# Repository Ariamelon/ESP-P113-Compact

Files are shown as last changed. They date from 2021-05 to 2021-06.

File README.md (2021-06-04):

# ESP-P113
 Compact version of ESP's Project 113 Amplifier done with SMT resistors and ceramic caps. PSU idea taken from https://theslowdiyer.wordpress.com/2019/09/10/project-files-filtered-irm-power-supplies-part-1/. Designed to go in sideways in this case (https://item.taobao.com/item.htm?id=54329725614). 

 ## Changelog
 ### V1
* 25/05/2021: Initial commit.
* 26/05/2021: Updated to V1.1. Added primary-side fuse, changed inductor to cheaper variant and rearranged components to make board even more compact. Updated BOM to match. Added extra M3 hole in middle of PCB and changed that hole to be the case grounding point instead.
* 27/05/2021: Updated to V1.2. Slightly changed position of transistors to allow for them to be mounted to an aluminium L-bracket and then to the case. 3mm power LEDs added. Changed output resistors to THT 0.5W versions. Added disclaimer on board. Moved position of components in CLC filter for more optimal routing.
 ### V2
* 29/05/2021: Updated to V2.0. A 220p compensation cap between opamp output and inverting input helped tame ringing on square waves with a 600R load with 10nF in parallel. A standard zobel network has also been added. Fixed major error with transistors (used wrong symbols/wrong way round, oops!). Added varistor between each power supply input and 3R resistor in series into live input, changed capacitor layout in output and added TVS diode to protect electronics in case converter fails as per CUI PSK-20D datasheet. 3.15A fuses into each live input will also be added off-board in the final design. Added gain switches to toggle gain resistance between 3k3 and 9k1 by switching 5k1 resistor in and out of parallel (actual resistance with both resistors in parallel is around 3k27, close enough), with option to choose between on-board DIP switches and off-board headers to use another switch. Output transistors changed to BD139/140. New layout, slightly larger but should still fit in planned case. Many thanks to user AnalogSteph on ASR for the help on the majority of the changes.
 ### V3
* 04/06/2021: Updated to V3.0. New layout with (hopefully) accurate measurements as drawings of case to be used have been received. Changed PSU to RAC20-15DK to save space and removed varistor. 200mA fuse will be used instead of 3.15A. Output BJTs changed to MJE15028/29s as they offer slightly better simulated distortion. The gain resistors have been changed to 560R/5k6 to allow for gain values of 1.5 and 6.6. PSU filter has been changed to CLC as that is more than adequate filtering. The DC protection and muting circuit from AMB has been added to protect the headphone out. On-board Y2 capacitor has been added for convenience. All SMT capacitors now also 1206 or 1210. Added 22kR/220pF RFI RC filter at the last second.

 ## Photos
Schematic
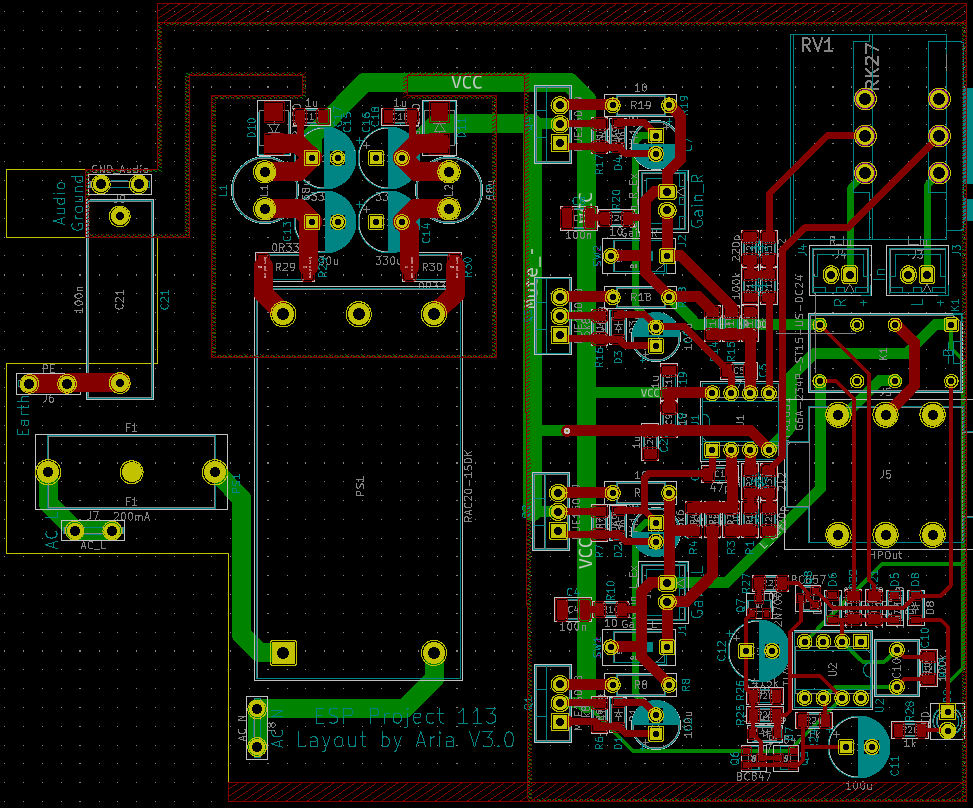
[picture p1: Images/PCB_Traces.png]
PCB Traces

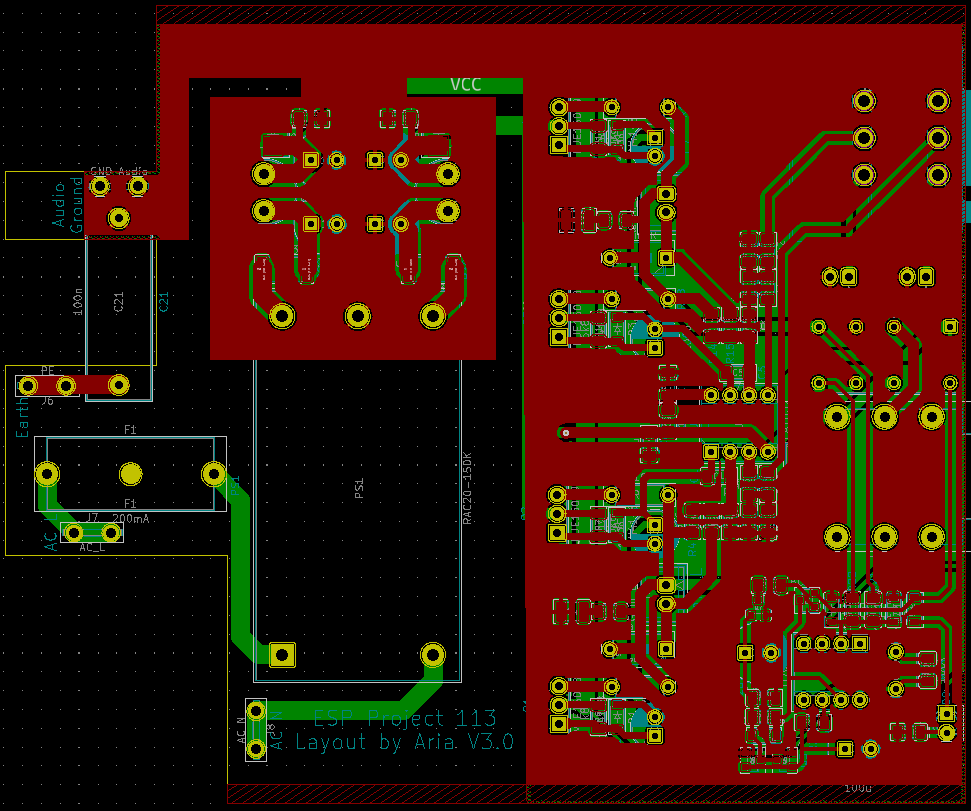
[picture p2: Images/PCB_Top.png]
Top PCB

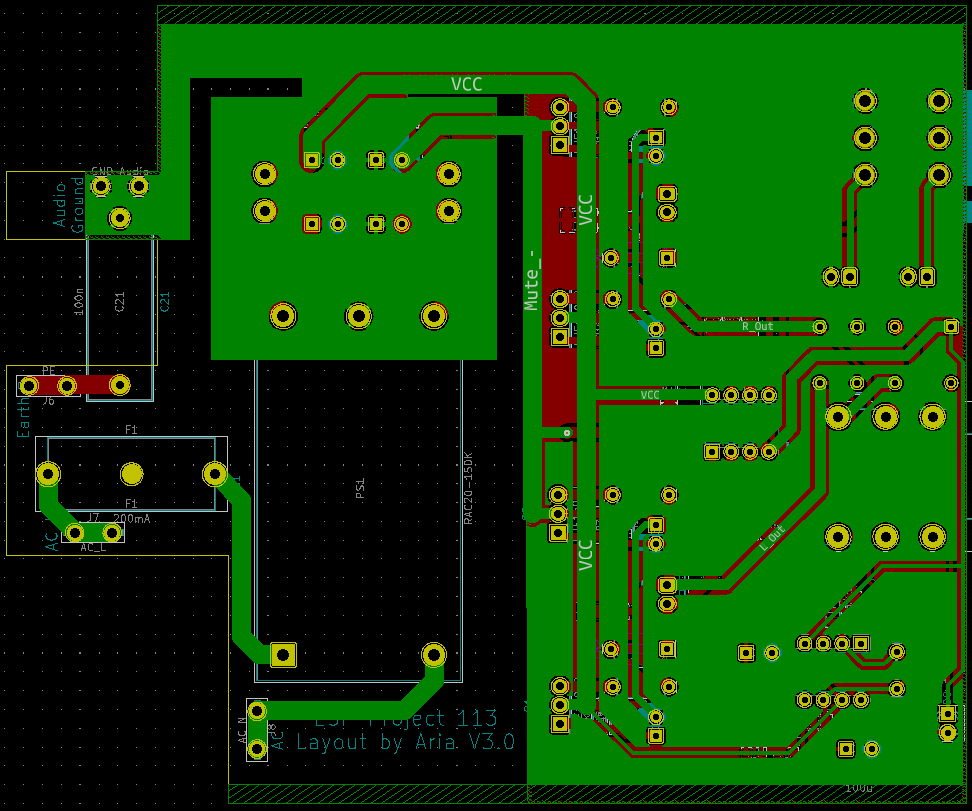
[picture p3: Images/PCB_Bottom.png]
Bottom PCB

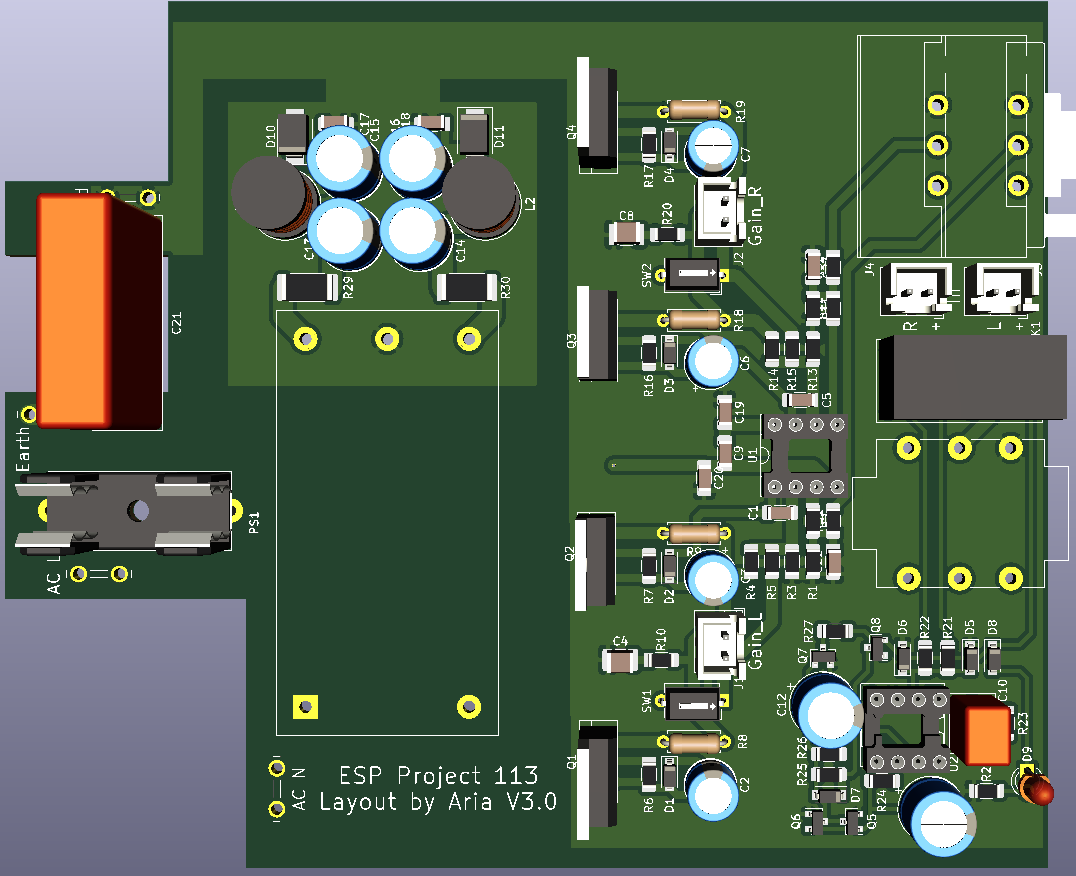
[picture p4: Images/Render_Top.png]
Top Render

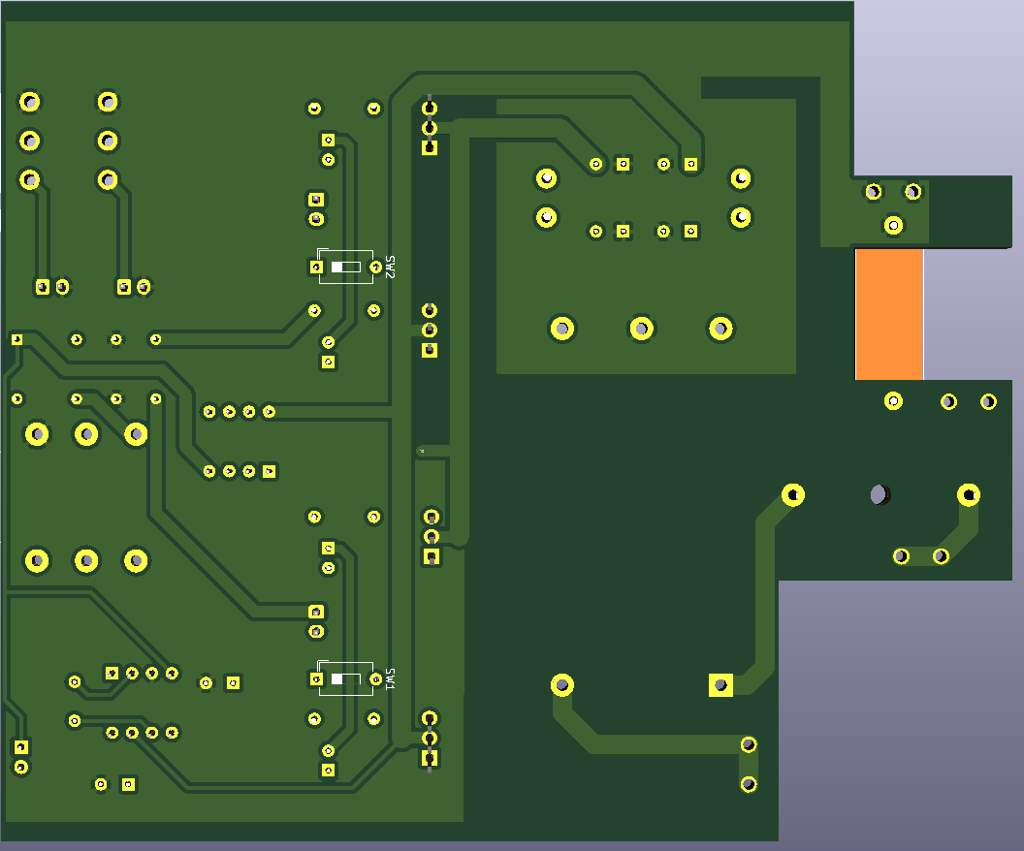
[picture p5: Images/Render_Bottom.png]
Bottom Render


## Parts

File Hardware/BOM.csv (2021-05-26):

Ref | Qnty | Value | Mfr. No | Package
C1, C5 | 2 | 1u | ECW-FE2W105JA | 18 x 5mm PP film cap, 15mm pin pacing
C2, C3, C4, C6, C7, C8, C12, C13 | 8 | 100u | EEU-FC1E101SB | 6.3mm diameter radial electrolytic, 2.5mm pin spacing
C9, C10, C11 | 3 | 100n | GCM21BR72A104KA37L | 0805 X7R capacitor
C14, C15, C16, C17 | 4 | 220u | EEU-FC1V221LB | 8mm diameter electrolytic, 3.5mm pin spacing
D1, D2, D3, D4 | 4 |  | 1N4148W-7-F | SOD-123 SMT diode
D5, D6 | 2 |  | LED_Small | 3mm LED
F1 | 1 |  | 31.8201 | 5 x 20mm fuse, greater than 0.17A
J1, J2, J3, J4 | 1 |  | B2B-XH-A(LF)(SN) | 2 position 2.54mm spacing XH2P JST connector
J5 | 1 |  | 1715721 | 2 position 5mm spacing phoenix terminal block
L1, L2 | 2 | 4u7 | TYS80404R7N-10 | 8 x 4 x 8mm inductor
PS1, PS2 | 2 | IRM-20-15 | IRM-20-15
Q1, Q3 | 2 | MJE15032 | MJE15032G | TO-220 NPN BJT
Q2, Q4 | 2 | MJE15033 | MJE15033G | TO-220 PNP BJT
R1, R9 | 2 | 22k | RT1206FRE0722KL | 1206 thin film resistor
R2, R3, R10, R11, R17, R18 | 6 | 1k | RT1206FRE071KL | 1206 thin film resistor
R4, R12 | 2 | 3k3 | RT1206FRE073K3L | 1206 thin film resistor
R5, R6, R13, R14 | 4 | 6k8 | RT1206FRE076K8L | 1206 thin film resistor
R7, R8, R15, R16 | 4 | 10 | RT1206FRE0710RL | 1206 thin film resistor
U1 | 1 | LM4562 | LM4562NA/NOPB | DIP-8 opamp

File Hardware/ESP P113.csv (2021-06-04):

Ref | Qty | Value | Cmp name | Description | Vendor
C1, C5, | 2 | 47p 50v 1% | 12061A470FAT2A | 1206 MLCC C0G/NP0
C2, C3, C6, C7, | 4 | 100u 25v 20% | EEU-FM1E101H | 6.3mmD x 11mmH x 2.5mmP radial electrolytic
C4, C8, | 2 | 100n 50v 5% | CB027D0104JBA | 1210 Metallized film
C9, C17, C18, C19, C20, | 5 | 1u 35v 20% | 1206DC105MAT2A | 1206 MLCC X7R
C10, | 1 | 1u 63v 10% | MKS2C041001F00KSSD | 7.2mmL x 5mmW x 10mmH x 5mmP radial box capacitor
C11, C12, | 2 | 100u 25v 20% | UVP1E101MPD1TA | 8mmD x 11.5mmH x 3.5mmP radial unpolarized electrolytic
C13, C14, C15, C16, | 4 | 330u 25v 20% | EEU-FC1E331L | 8mmD x 15mmH x 3.5mmP radial electrolytic, ESR is specially chosen
C21, | 1 | 100n 305vac 20% | F340Y241030MIM2T0 | 26mmL x 8.5mmW x 18mmH x 22.5mmP radial Y2 safety capacitor, MUST NOT BE X2
C22, C23, | 2 | 220p 6.3V 20% | 12063A221JAT2A | 1206 MLCC C0G/NP0
D1, D2, D3, D4, D5, D6, D7, D8, | 8 | 1Vf 4ns | MMSD914T3G | SOD-123 diode, must not have too high Vf and must have high recovery time
D9, | 1 | N/A | UV3TZ-405-30 | 3mm diode, choose any colour, I like purple lol
D10, D11, | 2 | 17v breakdown | SMBJ15D | TVS diode to protect circuit from voltage spikes
F1, | 1 | 200mA | 31.8201 | 5mmD x 20mmL fuse, slow-blow
J1, | 1 |  | XH2P | Optional, can use any 2.54mm pitch connector
J2, | 1 |  | XH2P | Optional, can use any 2.54mm pitch connector
J3, | 1 |  | XH2P | Optional, can use any 2.54mm pitch connector
J4, | 1 |  | XH2P | Optional, can use any 2.54mm pitch connector
J5, | 1 |  | NMJ6HCD2 | TRS socket
J6, | 1 |  | FastOn | Must be insulated
J7, | 1 |  | FastOn | Must be insulated
J8, | 1 |  | FastOn | Must be insulated
J9, | 1 |  | FastOn | Must be insulated
K1, | 1 | 2A max, 8.3mA coil, 10uA min load | G6A-234P-ST15-US-DC24 | Any relay which fits the same footprint and has similar specs can be used
L1, L2, | 2 | 68u 10% 1.2A 210mR | RLB0914-680KL | 8.7mmD x 12mmH x 5mmP Radial inductor
PS1, | 1 | +-15V 833mA each | RAC20-15DK | AC/DC converter
Q1, Q3, | 2 |  | MJE15028G | TO220 NPN BJT
Q2, Q4, | 2 |  | MJE15029G | TO220 PNP BJT
Q5, Q6, | 2 |  | BC847BW,135 | SOT-23 NPN BJT
Q7, | 1 |  | 2N7002NXAKR | SOT-23 NFET
Q8, | 1 |  | BC857BW,135 | SOT-23 PNP BJT
R1, R11, R23, | 3 | 100k 1% 250mW | RT1206FRE07100KL | 1206 thin film resistor
R2, R3, R12, R13, R24, R28, | 6 | 1k 1% 250mW | RT1206FRE071KL | 1206 thin film resistor
R4, R14, | 2 | 5k6 1% 250mW | RT1206FRE075K6L | 1206 thin film resistor
R5, R15, | 2 | 560 1% 250mW | RT1206FRE07560RL | 1206 thin film resistor
R6, R7, R16, R17, | 4 | 3k3 1% 250mW | RT1206FRE073K3L | 1206 thin film resistor
R8, R9, R18, R19, | 4 | 10 1% 500mW | MFR50SFTE52-10R | 2.4mmD x 6.3mmH axial metal film resistor
R10, R20, | 2 | 10 1% 250mW | RT1206FRE0710RL | 1206 thin film resistor
R21, R22, R27, | 3 | 10k | RT1206FRE0710KL | 1206 thin film resistor
R25, R26, | 2 | 475k 1% 250mW | RT1206FRE07475KL | 1206 thin film resistor
R29, R30, | 2 | 0R33 1% 2W 50PPM | KRL3264E-C-R330-F-T1 | 2512 metal foil resistor
R31, R32, | 2 | 22k 1% 250mW | RT1206FRE0722KL | 1206 thin film resistor
RV1, | 1 | 10k | RK27112 | Dual gang potentiometer
SW1, SW2, | 2 |  | NDI01H | Low profile DIP switch, optional
U1, | 1 |  | OPA1652AID | Replace with LM4562 or OPA1642 if desired
U2, | 1 |  | TL081CPE4 | Alternatives are TL072CP, LF353N or other low-cost dual FET opamps in a DIP-8 package
 | 4 |  | 274-1AB | These or other small heatsinks should be used for the output devices

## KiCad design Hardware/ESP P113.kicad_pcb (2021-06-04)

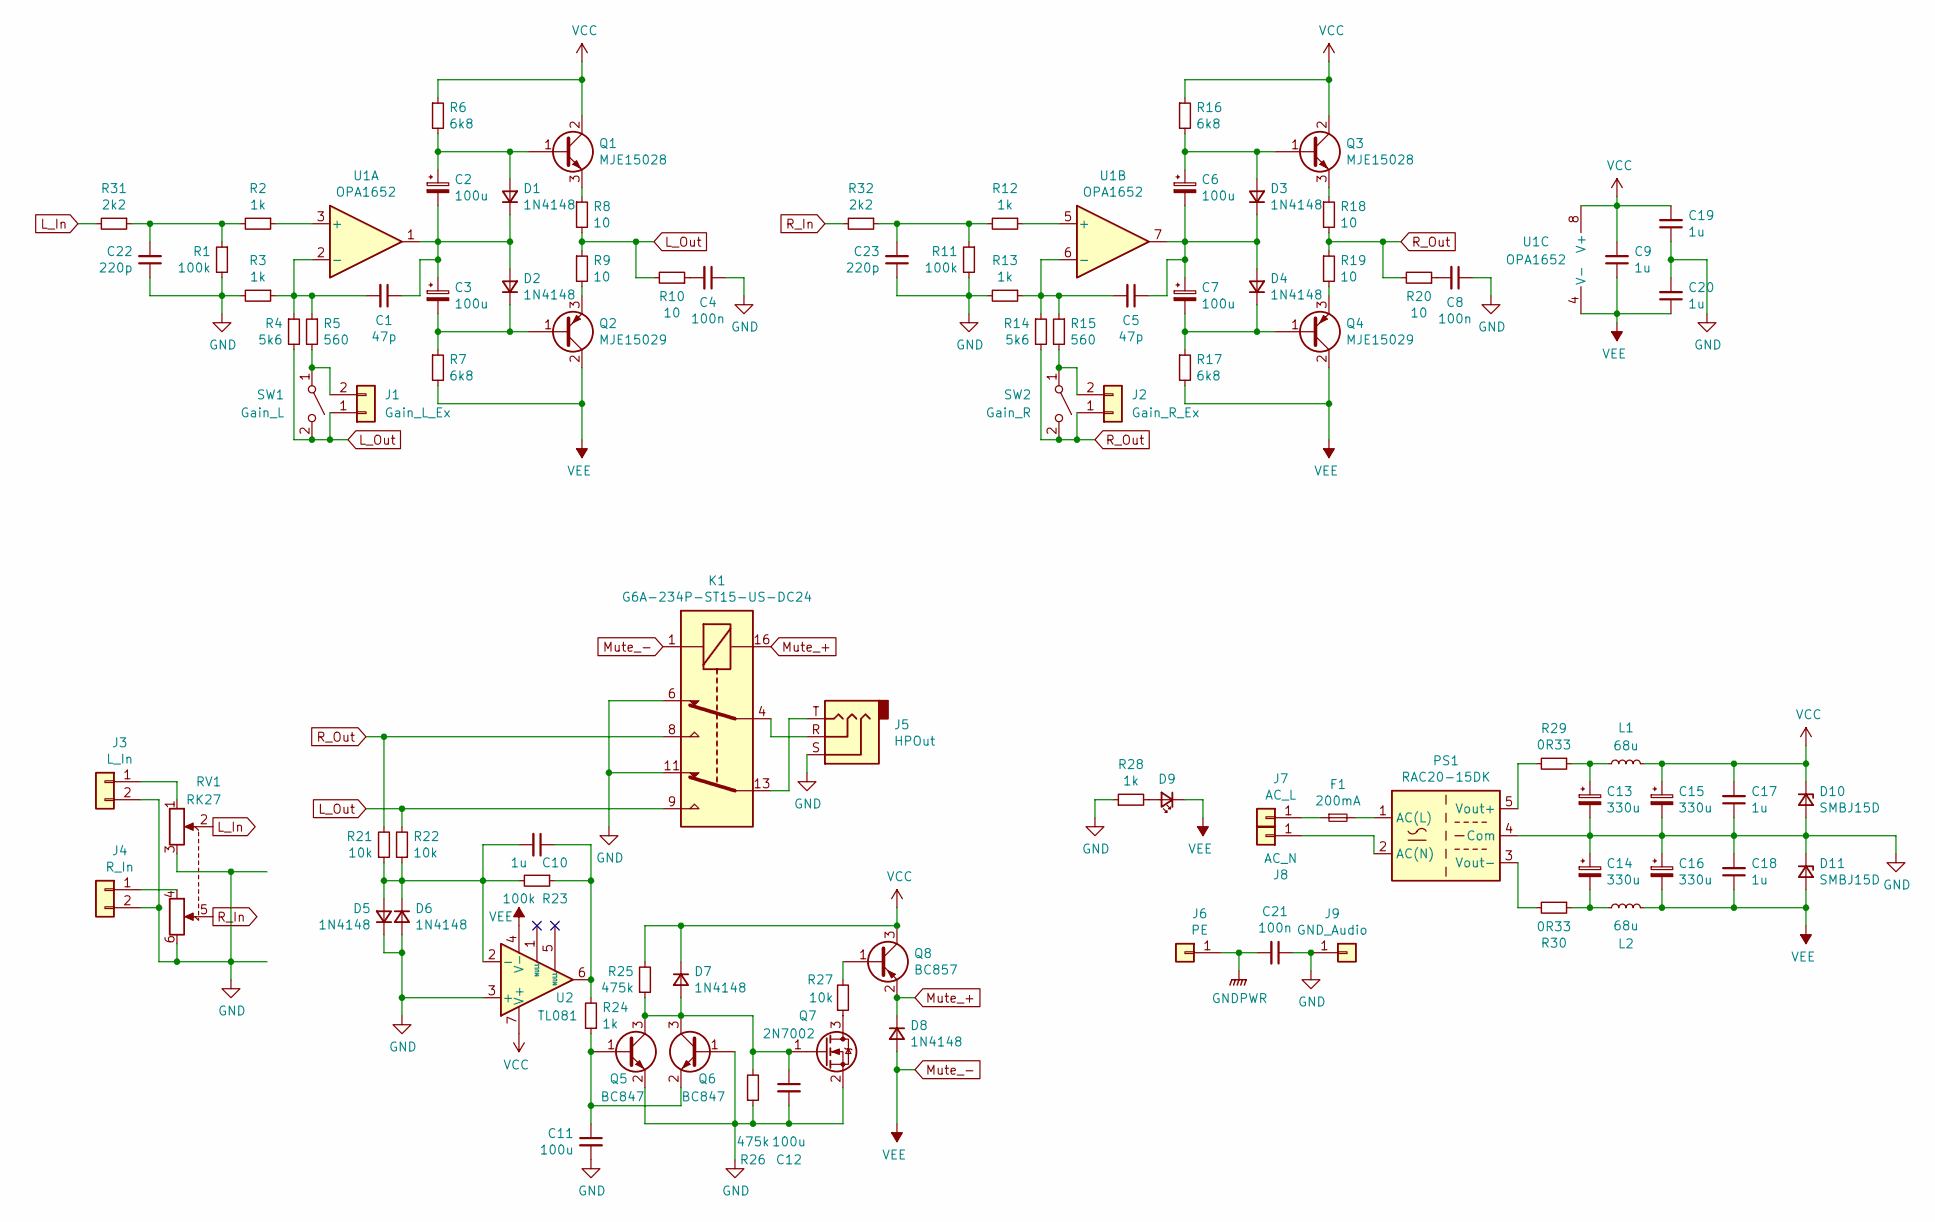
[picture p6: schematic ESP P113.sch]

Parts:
C1, C5: 47p; C_1206_3216Metric_Pad1.33x1.80mm_HandSolder
C2, C3, C6, C7: 100u; CP_Radial_D6.3mm_P2.50mm
C4, C8: 100n; C_1210_3225Metric_Pad1.33x2.70mm_HandSolder
C9, C17, C18, C19, C20: 1u; C_1206_3216Metric_Pad1.33x1.80mm_HandSolder
C10: 1u; C_Rect_L7.2mm_W5.5mm_P5.00mm_FKS2_FKP2_MKS2_MKP2
C11, C12: 100u; CP_Radial_D8.0mm_P3.50mm
C13, C14, C15, C16: 330u; CP_Radial_D8.0mm_P3.50mm
C21: 100n; C_Rect_L26.5mm_W8.5mm_P22.50mm_MKS4
C22, C23: 220p; C_1206_3216Metric_Pad1.33x1.80mm_HandSolder
D1, D2, D3, D4, D5, D6, D7, D8: 1N4148; D_SOD-123
D9: LED; LED_D3.0mm
D10, D11: SMBJ15D; D_SMB
F1: 200mA; Fuseholder_Cylinder-5x20mm_Schurter_0031_8201_Horizontal_Op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
J1: Gain_L_Ex; JST_XH_B2B-XH-A_1x02_P2.50mm_Vertical
J2: Gain_R_Ex; JST_XH_B2B-XH-A_1x02_P2.50mm_Vertical
J3: L_In; JST_XH_B2B-XH-A_1x02_P2.50mm_Vertical
J4: R_In; JST_XH_B2B-XH-A_1x02_P2.50mm_Vertical
J5: HPOut; Jack_6.35mm_Neutrik_NMJ6HCD2_Horizontal
J6: PE; FastOn
J7: AC_L; FastOn
J8: AC_N; FastOn
J9: GND_Audio; FastOn
K1: G6A-234P-ST15-US-DC24; Relay_DPDT_Omron_G5V-2
L1, L2: 68u; L_Radial_D8.7mm_P5.00mm_Fastron_07HCP
PS1: RAC20-15DK; Converter_ACDC_RACx0-DK_THT
Q1, Q3: MJE15028; TO-220-3_Vertical
Q2, Q4: MJE15029; TO-220-3_Vertical
Q5, Q6: BC847; SOT-23
Q7: 2N7002; SOT-23
Q8: BC857; SOT-23
R1, R11, R23: 100k; R_1206_3216Metric_Pad1.30x1.75mm_HandSolder
R2, R3, R12, R13, R24, R28: 1k; R_1206_3216Metric_Pad1.30x1.75mm_HandSolder
R4, R14: 5k6; R_1206_3216Metric_Pad1.30x1.75mm_HandSolder
R5, R15: 560; R_1206_3216Metric_Pad1.30x1.75mm_HandSolder
R6, R7, R16, R17: 6k8; R_1206_3216Metric_Pad1.30x1.75mm_HandSolder
R8, R9, R18, R19: 10; R_Axial_DIN0207_L6.3mm_D2.5mm_P7.62mm_Horizontal
R10, R20: 10; R_1206_3216Metric_Pad1.30x1.75mm_HandSolder
R21, R22, R27: 10k; R_1206_3216Metric_Pad1.30x1.75mm_HandSolder
R25, R26: 475k; R_1206_3216Metric_Pad1.30x1.75mm_HandSolder
R29, R30: 0R33; R_2512_6332Metric_Pad1.40x3.35mm_HandSolder
R31, R32: 2k2; R_1206_3216Metric_Pad1.30x1.75mm_HandSolder
RV1: RK27; ALPS_RK27112
SW1: Gain_L; SW_DIP_SPSTx01_Slide_6.7x4.1mm_W7.62mm_P2.54mm_LowProfile
SW2: Gain_R; SW_DIP_SPSTx01_Slide_6.7x4.1mm_W7.62mm_P2.54mm_LowProfile
U1: OPA1652; DIP-8_W7.62mm_Socket
U2: TL081; DIP-8_W7.62mm_Socket

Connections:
GND: C4.1, C8.1, C11.2, C12.2, C13.2, C14.1, C15.2, C16.1, C17.1, C18.2, C19.1, C20.2, C21.1, C22.1, C23.1, D5.1 (K), D6.2 (A), D10.2 (A), D11.1 (K), J3.2, J4.2, J5.S, J9.1, K1.6, K1.11, PS1.4 (Com), Q5.2 (E), Q6.1 (B), Q7.2 (S), R1.2, R3.2, R11.2, R13.2, R26.1, R28.1, RV1.3, RV1.6, U2.3 (+)
GNDPWR: C21.2, J6.1
L_In: R31.2, RV1.2
L_Out: J1.1, K1.9, R4.2, R8.2, R9.1, R10.2, R22.2, SW1.2 (B)
Mute_+: D8.1 (K), K1.16, Q8.2 (E)
Mute_-: C9.1, C16.2, C18.1, C20.1, D8.2 (A), D9.1 (K), D11.2 (A), K1.1, L2.2, Q2.2 (C), Q4.2 (C), R7.2, R17.2, U1.4 (V-), U2.4 (V-)
unnamed: C1.1, C2.2, C3.1, D1.1 (K), D2.2 (A), U1.1
unnamed: C1.2, R3.1, R4.1, R5.1, U1.2 (-)
unnamed: C2.1, D1.2 (A), Q1.1 (B), R6.2
unnamed: C3.2, D2.1 (K), Q2.1 (B), R7.1
unnamed: C4.2, R10.1
unnamed: C5.1, C6.2, C7.1, D3.1 (K), D4.2 (A), U1.7
unnamed: C5.2, R13.1, R14.1, R15.1, U1.6 (-)
unnamed: C6.1, D3.2 (A), Q3.1 (B), R16.2
unnamed: C7.2, D4.1 (K), Q4.1 (B), R17.1
unnamed: C8.2, R20.1
unnamed: C10.1, R23.1, R24.2, U2.6
unnamed: C10.2, D5.2 (A), D6.1 (K), R21.1, R22.1, R23.2, U2.2 (-)
unnamed: C11.1, Q5.1 (B), Q6.2 (E), R24.1
unnamed: C12.1, D7.2 (A), Q5.3 (C), Q6.3 (C), Q7.1 (G), R25.1, R26.2
unnamed: C13.1, L1.1, R29.1
unnamed: C14.2, L2.1, R30.1
unnamed: C22.2, R1.1, R2.2, R31.1
unnamed: C23.2, R11.1, R12.2, R32.1
unnamed: D9.2 (A), R28.2
unnamed: F1.1, J7.1
unnamed: F1.2, PS1.1 (AC(L))
unnamed: J1.2, R5.2, SW1.1 (A)
unnamed: J2.2, R15.2, SW2.1 (A)
unnamed: J3.1, RV1.1
unnamed: J4.1, RV1.4
unnamed: J5.R, K1.4
unnamed: J5.T, K1.13
unnamed: J8.1, PS1.2 (AC(N))
unnamed: PS1.3 (Vout-), R30.2
unnamed: PS1.5 (Vout+), R29.2
unnamed: Q1.3 (E), R8.1
unnamed: Q2.3 (E), R9.2
unnamed: Q3.3 (E), R18.1
unnamed: Q4.3 (E), R19.2
unnamed: Q7.3 (D), R27.1
unnamed: Q8.1 (B), R27.2
unnamed: R2.1, U1.3 (+)
unnamed: R12.1, U1.5 (+)
R_In: R32.2, RV1.5
R_Out: J2.1, K1.8, R14.2, R18.2, R19.1, R20.2, R21.2, SW2.2 (B)
VCC: C9.2, C15.1, C17.2, C19.2, D7.1 (K), D10.1 (K), L1.2, Q1.2 (C), Q3.2 (C), Q8.3 (C), R6.1, R16.1, R25.2, U1.8 (V+), U2.7 (V+)

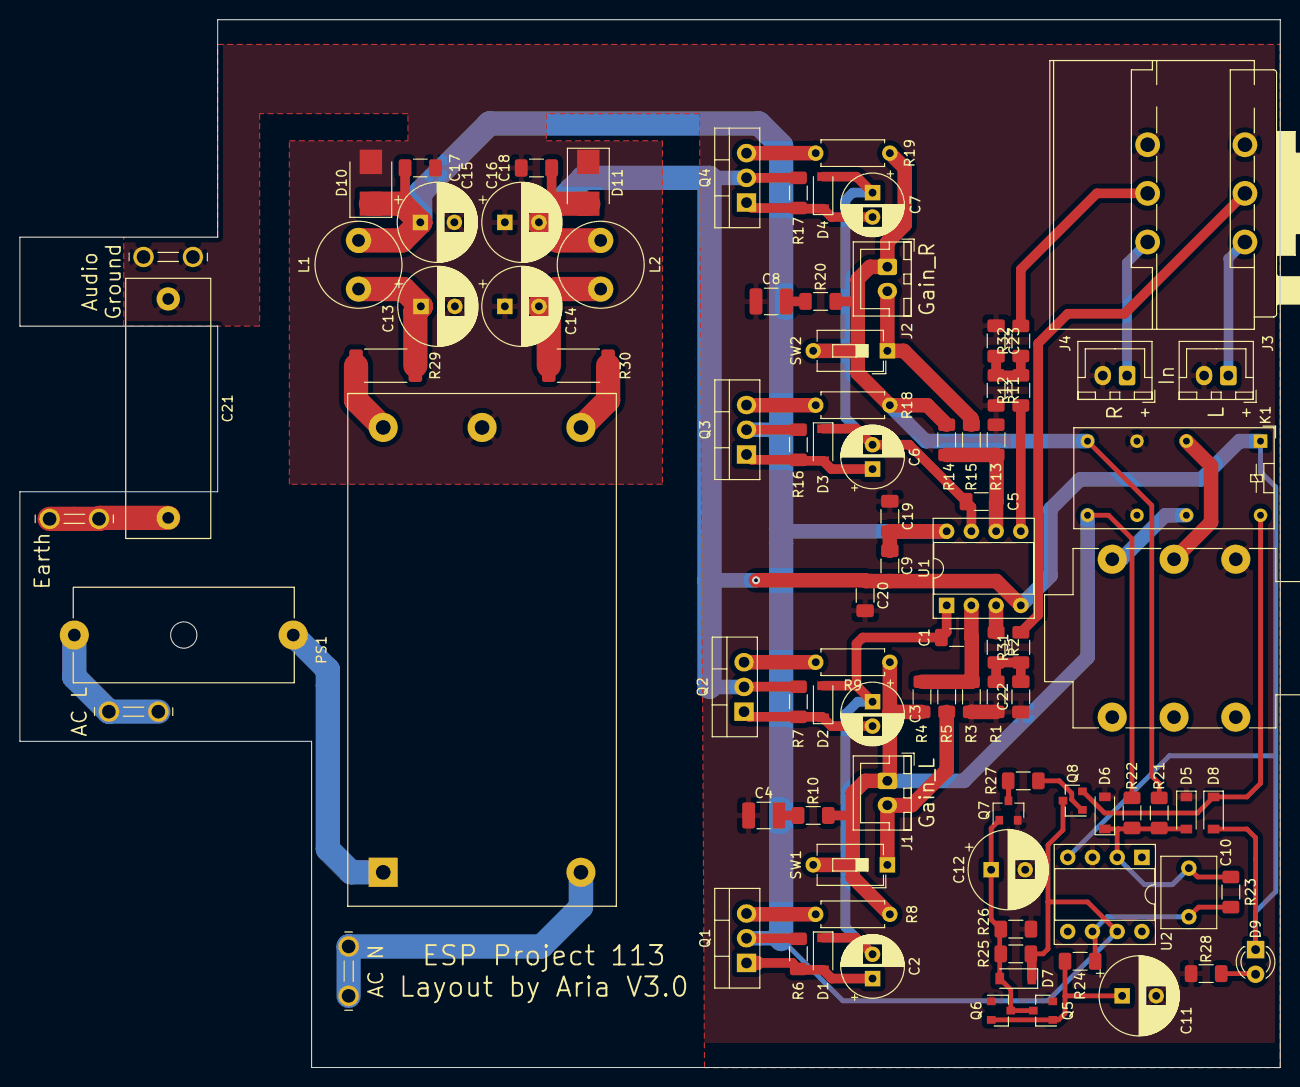
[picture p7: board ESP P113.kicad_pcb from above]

Board: 2 copper layers, 129.5 x 107.7 mm, 93 parts (0 on the bottom side), 47 nets.

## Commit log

2021-05-25 Deleted old BOM and added images to readme
    [ESP P113fasdfsdf.csv]
2021-05-26 Updated to V1.1
    [ESP P113.csv, ESP P113.kicad_pcb, ESP P113.sch]
2021-05-26 Removed ground plane from PSU area
    [BOM.csv, ESP P113.kicad_pcb]
2021-05-26 Updated to V1.2.
    [BOM.csv, ESP P113.kicad_pcb, ESP P113.sch]
2021-05-27 Added version with no PSU
    [BOM.csv, ESP P113.kicad_pcb, ESP P113.sch]
2021-05-27 Fixed image links, updated BOM
    [BOM.csv, ESP P113.kicad_pcb, ESP P113.sch]
2021-05-27 Fixed amp only schematic
    [ESP P113.kicad_pcb, ESP P113.sch]
2021-05-27 Slightly moved position of output resistors.
    [BOM.csv, ESP P113.csv, ESP P113.kicad_pcb]
2021-05-27 Revert "Slightly moved position of output resistors."
    This reverts commit 2c67a83915dd1cff94a26fcd4de2be662b6489d6.
    [BOM.csv, ESP P113.csv, ESP P113.kicad_pcb]
2021-05-27 Changed output resistors to THT 0.5W versions. Removed amp-only version. Added disclaimer on board.
    [BOM.csv, ESP P113.csv, ESP P113.kicad_pcb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]
2021-05-27 Moved position of components in CLC filter for more optimal routing.
    [ESP P113.kicad_pcb]
2021-05-28 Updated to V2.0.
    [ESP P113.csv, ESP P113.kicad_pcb, ESP P113.sch]
2021-05-29 Changed layout
    [ESP P113.kicad_pcb, ESP P113.sch]
2021-05-29 Minor correction
    [ESP P113.kicad_pcb, ESP P113.sch]
2021-06-04 Updated to V3.0.
    [ESP P113.kicad_pcb, ESP P113.sch]
2021-06-04 Updated layout, re-added BOM.
    [ESP P113.csv, ESP P113.kicad_pcb, ESP P113.sch]
2021-06-04 Added RFI filter.
    [ESP P113.kicad_pcb, ESP P113.sch]
2021-06-04 Updated BOM.
    [ESP P113.csv]
